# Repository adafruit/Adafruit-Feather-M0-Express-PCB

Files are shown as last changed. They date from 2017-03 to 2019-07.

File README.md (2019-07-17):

## Adafruit Feather M0 Express - Designed for CircuitPython - ATSAMD21 Cortex M0 PCB

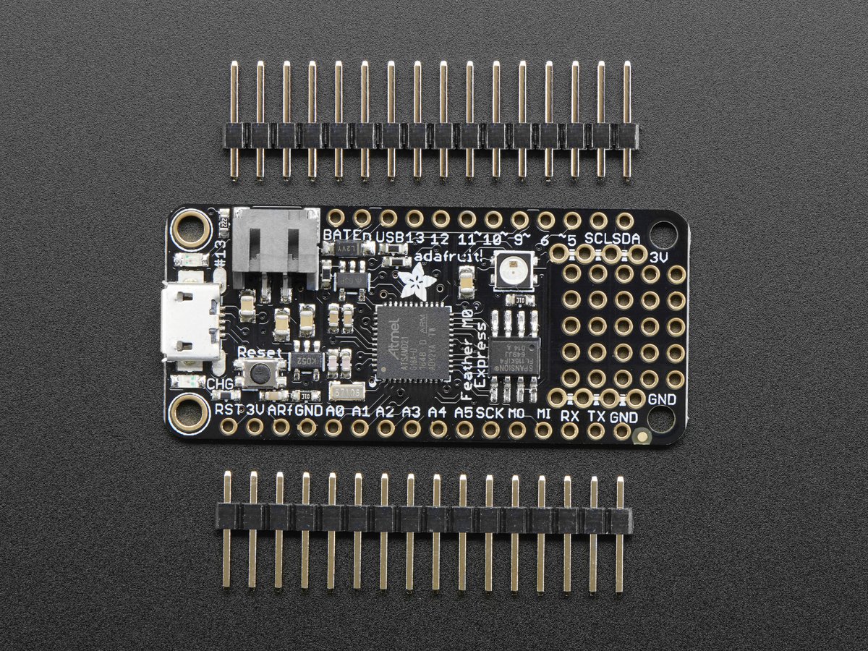
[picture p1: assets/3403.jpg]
<a href="http://www.adafruit.com/products/3403"><br/>
Click here to purchase one from the Adafruit shop</a>

PCB files for the Adafruit Feather M0 Express - Designed for CircuitPython - ATSAMD21 Cortex M0. Format is EagleCAD schematic and board layout
* https://www.adafruit.com/product/3403

### Description

We love all our Feathers equally, but this Feather is very special. It's our first Feather that is specifically designed for use with CircuitPython! CircuitPython is our beginner-oriented flavor of MicroPython - and as the name hints at, its a small but full-featured version of the popular Python programming language specifically for use with circuitry and electronics.

Please note, CircuitPython does not come preloaded. See the full guide linked below for instructions on installing it.

That doesn't mean you cant also use it with Arduino IDE! At the Feather M0's heart is an ATSAMD21G18 ARM Cortex M0+ processor, clocked at 48 MHz and at 3.3V logic, the same one used in the new [Arduino Zero](https://www.adafruit.com/products/2843). This chip has a whopping 256K of FLASH (8x more than the Atmega328 or 32u4) and 32K of RAM (16x as much)! This chip comes with built in USB so it has USB-to-Serial program & debug capability built in with no need for an FTDI-like chip.

**Here's some handy specs!**
 * Measures 2.0" x 0.9" x 0.28" (51mm x 23mm x 8mm) without headers soldered in
 * Light as a (large?) feather - 5 grams
 * ATSAMD21G18 @ 48MHz with 3.3V logic/power
 * 256KB of FLASH + 32KB of RAM
 * No EEPROM
 * 32.768 KHz crystal for clock generation & RTC
 * 3.3V regulator with 500mA peak current output
 * USB native support, comes with USB bootloader and serial port debugging
 * You also get tons of pins - 20 GPIO pins
 * Hardware Serial, hardware I2C, hardware SPI support
 * PWM outputs on all pins
 * 6 x 12-bit analog inputs
 * 1 x 10-bit analog ouput (DAC)
 * Built in 100mA lipoly charger with charging status indicator LED
 * Pin #13 red LED for general purpose blinking
 * Power/enable pin
 * 4 mounting holes
 * Reset button

The **Feather M0 Express** uses the extra space left over to add a **Mini NeoPixel, 2 MB SPI Flash** storage and a little prototyping space. You can use the SPI Flash storage like a very tiny hard drive. When used in CircuitPython, the 2 MB flash acts as storage for all your scripts, libraries and files. When used in Arduino, you can read/write files to it, like a little datalogger or SD card, and then with our helper program, access the files over USB.

**Easy reprogramming**: the Feather M0 comes pre-loaded with the [UF2 bootloader](https://learn.adafruit.com/adafruit-feather-m0-express-designed-for-circuit-python-circuitpython/uf2-bootloader), which looks like a USB storage key. Simply drag firmware on to program, no special tools or drivers needed! It can be used to load up CircuitPython, PXT MakeCode or Arduino IDE (it is bossa-compatible)

Comes fully assembled and tested, with the UF2 USB bootloader. We also toss in some header so you can solder it in and plug into a solderless breadboard. 

**Lipoly battery and USB cable not included** (but we do have lots of options in the shop if you'd like!)

[Wanna get started with this fancy new Feather? We have a full guide with details on using it with both Arduino IDE and CircuitPython. The guide also has wiring information, drivers, Fritzing objects, schematics, datasheets and more!](https://learn.adafruit.com/adafruit-feather-m0-express-designed-for-circuit-python-circuitpython)

### License

Adafruit invests time and resources providing this open source design, please support Adafruit and open-source hardware by purchasing products from [Adafruit](https://www.adafruit.com)!

Designed by Limor Fried/Ladyada for Adafruit Industries.

Creative Commons Attribution/Share-Alike, all text above must be included in any redistribution. See license.txt for additional details.

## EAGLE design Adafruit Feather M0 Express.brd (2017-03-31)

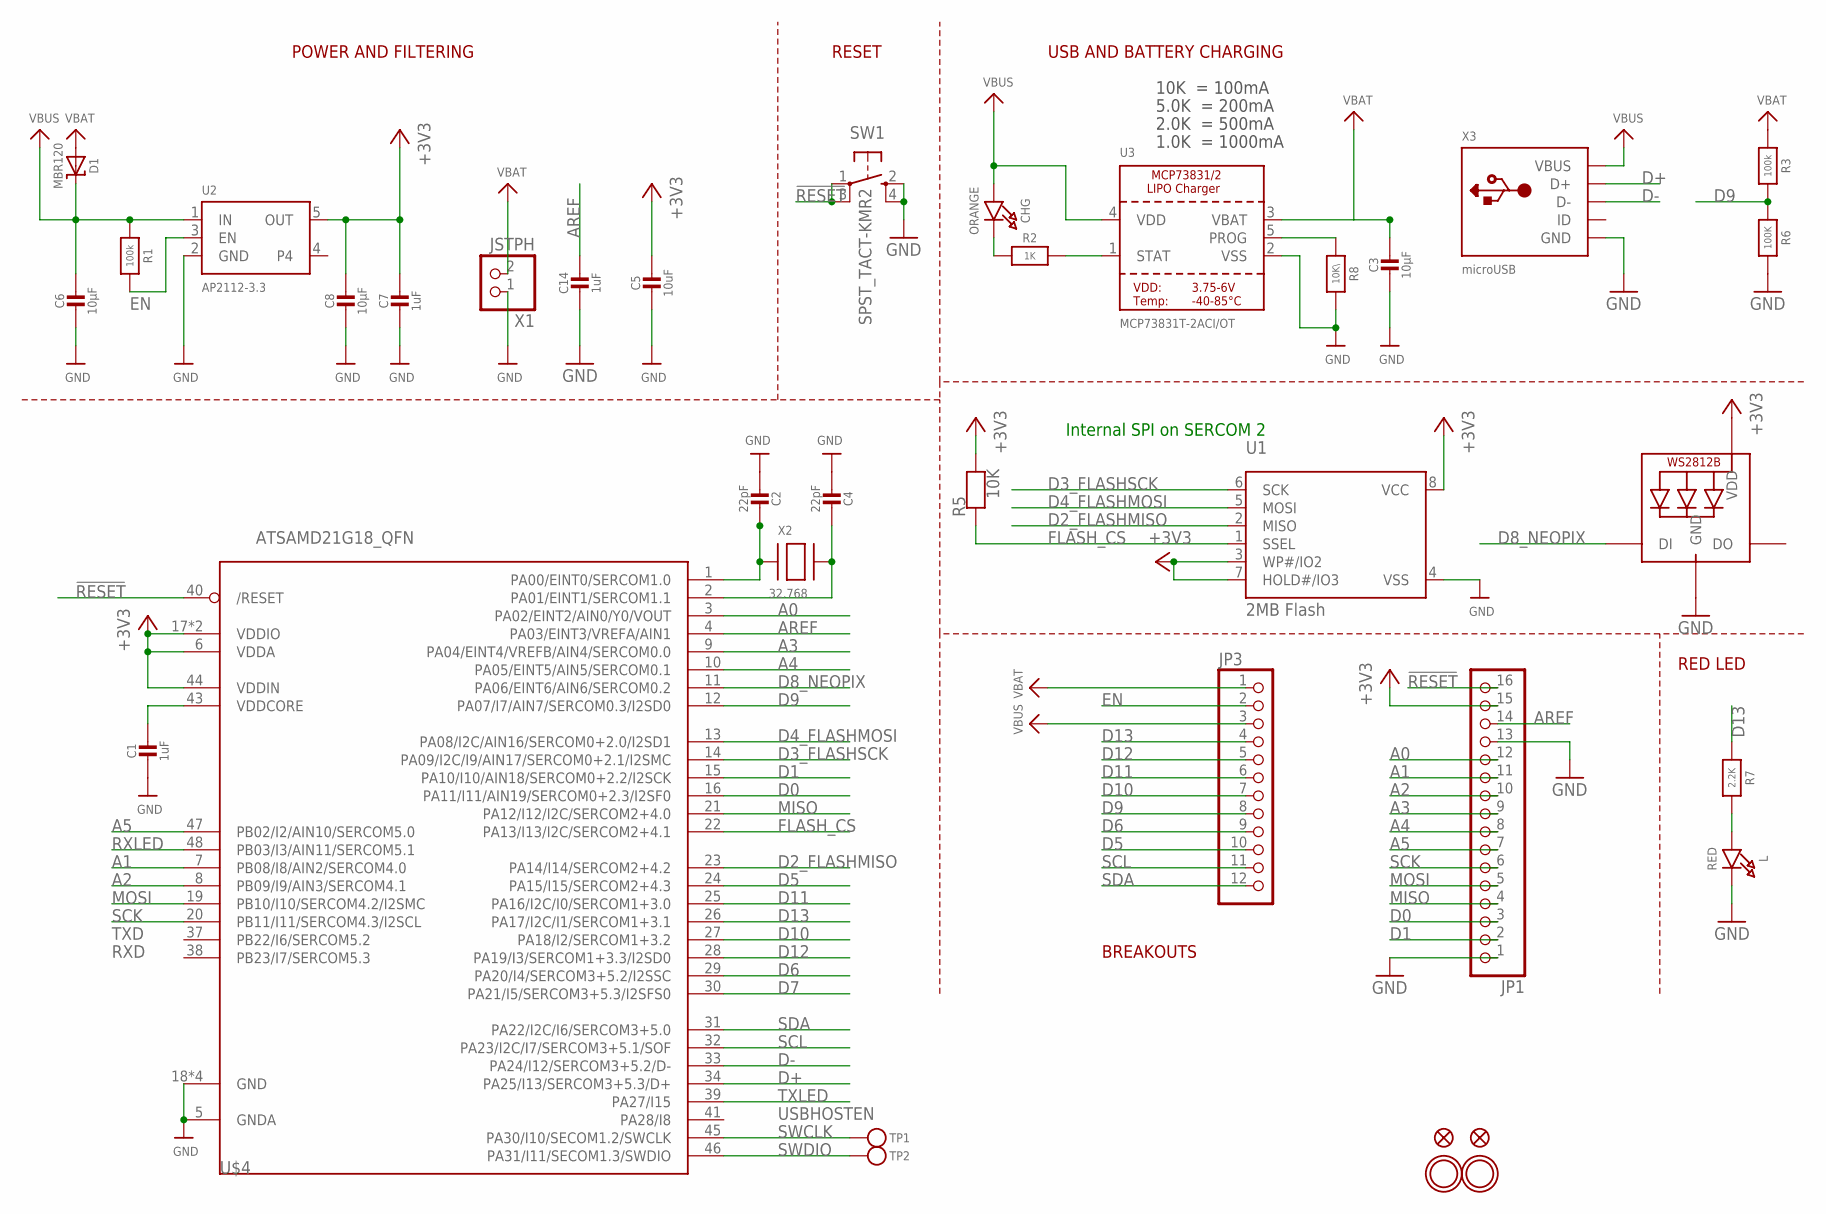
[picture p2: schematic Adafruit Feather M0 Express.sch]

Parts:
C1, C7, C14: 1uF; 0603-NO
C2, C4: 22pF; 0603-NO
C3, C6, C8: 10µF; 0805-NO
C5: 10uF; 0805-NO
CHG: ORANGE; CHIPLED_0805_NOOUTLINE
D1: MBR120; SOD-123
JP1: HEADER-1X16ROUND; 1X16_ROUND
JP3: HEADER-1X12; 1X12_ROUND
L: RED; CHIPLED_0805_NOOUTLINE
LED1: WS2812B3535; LED3535
R1, R3: 100k; 0603-NO
R2: 1K; 0603-NO
R5: 10K; 0603-NO
R6: 100K; 0603-NO
R7: 2.2K; 0603-NO
R8: 10K\; 0603-NO
SW1: SPST_TACT-KMR2; KMR2
TP1, TP2: TESTPOINTROUND1.5MM; TESTPOINT_ROUND_1.5MM
U1: 2MB Flash; SOIC8_208MIL
U2: AP2112-3.3; SOT23-5
U3: MCP73831T-2ACI/OT; SOT23-5
U$4: ATSAMD21G18_QFN; TQFN48_7MM
U$31, U$32: MOUNTINGHOLE2.5; MOUNTINGHOLE_2.5_PLATED
U$34, U$35: FIDUCIAL""; FIDUCIAL_1MM
X1: JSTPH; JSTPH2
X2: 32.768; XTAL3215
X3: microUSB; 4UCONN_20329_V2

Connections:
!RESET: JP1.16, SW1.1, SW1.3 (P1), U$4.40 (/RESET)
+3V3: C5.1, C7.1, C8.1, JP1.15, LED1.2 (VDD), R5.2, U1.3 (WP#/IO2), U1.7 (HOLD#/IO3), U1.8 (VCC), U2.5 (OUT), U$4.6 (VDDA), U$4.17 (VDDIO), U$4.36 (VDDIO), U$4.44 (VDDIN)
A0: JP1.12, U$4.3 (PA02/EINT2/AIN0/Y0/VOUT)
A1: JP1.11, U$4.7 (PB08/I8/AIN2/SERCOM4.0)
A2: JP1.10, U$4.8 (PB09/I9/AIN3/SERCOM4.1)
A3: JP1.9, U$4.9 (PA04/EINT4/VREFB/AIN4/SERCOM0.0)
A4: JP1.8, U$4.10 (PA05/EINT5/AIN5/SERCOM0.1)
A5: JP1.7, U$4.47 (PB02/I2/AIN10/SERCOM5.0)
AREF: C14.1, JP1.14, U$4.4 (PA03/EINT3/VREFA/AIN1)
D0: JP1.3, U$4.16 (PA11/I11/AIN19/SERCOM0+2.3/I2SF0)
D1: JP1.2, U$4.15 (PA10/I10/AIN18/SERCOM0+2.2/I2SCK)
D2_FLASHMISO: U1.2 (MISO), U$4.23 (PA14/I14/SERCOM2+4.2)
D3_FLASHSCK: U1.6 (SCK), U$4.14 (PA09/I2C/I9/AIN17/SERCOM0+2.1/I2SMC)
D4_FLASHMOSI: U1.5 (MOSI), U$4.13 (PA08/I2C/AIN16/SERCOM0+2.0/I2SD1)
D5: JP3.10, U$4.24 (PA15/I15/SERCOM2+4.3)
D6: JP3.9, U$4.29 (PA20/I4/SERCOM3+5.2/I2SSC)
D7: U$4.30 (PA21/I5/SERCOM3+5.3/I2SFS0)
D8_NEOPIX: LED1.1 (DI), U$4.11 (PA06/EINT6/AIN6/SERCOM0.2)
D9: JP3.8, R3.2, R6.1, U$4.12 (PA07/I7/AIN7/SERCOM0.3/I2SD0)
D10: JP3.7, U$4.27 (PA18/I2/SERCOM1+3.2)
D11: JP3.6, U$4.25 (PA16/I2C/I0/SERCOM1+3.0)
D12: JP3.5, U$4.28 (PA19/I3/SERCOM1+3.3/I2SD0)
D13: JP3.4, R7.1, U$4.26 (PA17/I2C/I1/SERCOM1+3.1)
D+: U$4.34 (PA25/I13/SERCOM3+5.3/D+), X3.D+
D-: U$4.33 (PA24/I12/SERCOM3+5.2/D-), X3.D-
EN: JP3.2, R1.2, U2.3 (EN)
FLASH_CS: R5.1, U1.1 (SSEL), U$4.22 (PA13/I13/I2C/SERCOM2+4.1)
GND: C1.2, C2.2, C3.2, C4.2, C5.2, C6.2, C7.2, C8.2, C14.2, JP1.1, JP1.13, L.C, LED1.4 (GND), R6.2, R8.2, SW1.2 (S), SW1.4 (S1), U1.4 (VSS), U2.2 (GND), U3.2 (VSS), U$4.5 (GNDA), U$4.18 (GND), U$4.35 (GND), U$4.42 (GND), U$4.THERMAL (GND), X1.1, X3.BASE@1 (GND), X3.BASE@2 (GND), X3.GND, X3.SPRT@1 (GND), X3.SPRT@2 (GND), X3.SPRT@3 (GND), X3.SPRT@4 (GND)
MISO: JP1.4, U$4.21 (PA12/I12/I2C/SERCOM2+4.0)
MOSI: JP1.5, U$4.19 (PB10/I10/SERCOM4.2/I2SMC)
unnamed: CHG.C, R2.1
unnamed: L.A, R7.2
unnamed: R2.2, U3.1 (STAT)
unnamed: R8.1, U3.5 (PROG)
unnamed: C2.1, U$4.1 (PA00/EINT0/SERCOM1.0), X2.P$1
unnamed: C4.1, U$4.2 (PA01/EINT1/SERCOM1.1), X2.P$2
RXLED: U$4.48 (PB03/I3/AIN11/SERCOM5.1)
SCK: JP1.6, U$4.20 (PB11/I11/SERCOM4.3/I2SCL)
SCL: JP3.11, U$4.32 (PA23/I2C/I7/SERCOM3+5.1/SOF)
SDA: JP3.12, U$4.31 (PA22/I2C/I6/SERCOM3+5.0)
SWCLK: TP1.P$1, U$4.45 (PA30/I10/SECOM1.2/SWCLK)
SWDIO: TP2.P$1, U$4.46 (PA31/I11/SECOM1.3/SWDIO)
TXLED: U$4.39 (PA27/I15)
VBAT: C3.1, D1.A, JP3.1, R3.1, U3.3 (VBAT), X1.2
VBUS: C6.1, CHG.A, D1.C, JP3.3, R1.1, U2.1 (IN), U3.4 (VDD), X3.VBUS
VDDCORE: C1.1, U$4.43 (VDDCORE)

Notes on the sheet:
POWER AND FILTERING
RESET
10K = 100mA
5.0K = 200mA
2.0K = 500mA
1.0K = 1000mA
USBHOSTEN
TXD
RXD
USB AND BATTERY CHARGING
BREAKOUTS
RED LED
Internal SPI on SERCOM 2

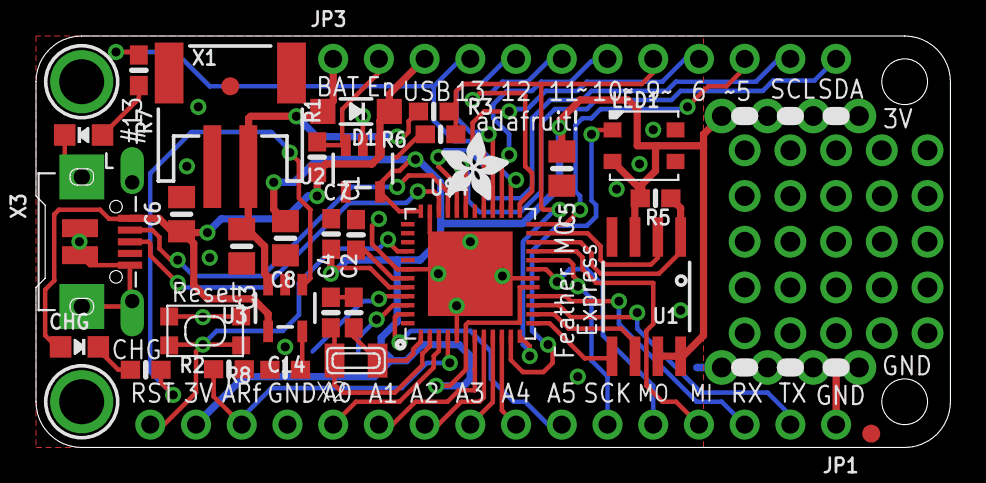
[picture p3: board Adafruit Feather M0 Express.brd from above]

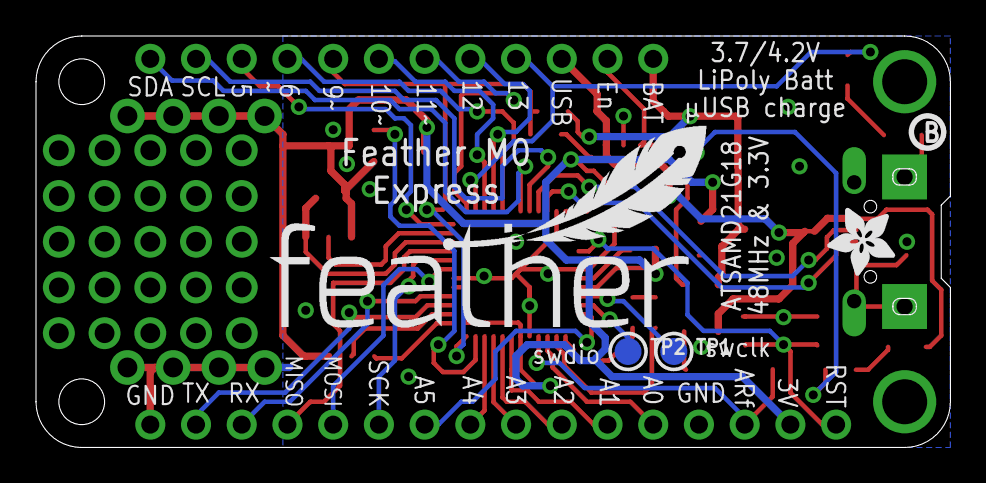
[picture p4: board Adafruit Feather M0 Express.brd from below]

Board: 2 copper layers, 50.8 x 22.9 mm, 40 parts (5 on the bottom side), 43 nets.

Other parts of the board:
U$7, U$12: ADAFRUIT_3.5MM
U$9: FEATHERLOGO
U$13: PCBFEAT-REV-040

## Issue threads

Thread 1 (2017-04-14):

PDF schematics?

ianrrees, 2017-04-14:
Hello!  It would be great if there were a pdf(?) of the schematic here, for folks who don't have Eagle installed for whatever reason.  I'm a KiCad user, and can't quite read the schematic in [this manual](https://cdn-learn.adafruit.com/downloads/pdf/adafruit-feather-m0-express-designed-for-circuit-python-circuitpython.pdf).

I would be glad to make a PR that adds a PDF if that would be accepted?

ladyada, 2017-04-14:
schematic here
https://learn.adafruit.com/bluefruit-nrf52-feather-learning-guide/arduino-bsp-setup?view=all#schematic

ianrrees, 2017-04-14:
Thanks for the quick response!  That schematic is for a different board, but I think I can figure out what I wanted to know from the photos anyways (or just be patient and wait for mine to arrive...).  Looking forward to experimenting with micropython!

caternuson, 2017-04-14:
Check out the 'Downloads' page for a given product's guide. That's where most of this stuff tries to live.

https://learn.adafruit.com/adafruit-feather-m0-express-designed-for-circuit-python-circuitpython/downloads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

ladyada, 2017-04-14:
thanks - that was the right link! we have a lot of feathers :)

Closed 2017-04-14.

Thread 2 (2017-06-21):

Feater M0 Express out of the Box on Win8, no USB Mass Storage in bootmode

mindforger, 2017-06-21:
I followed the guide, plugged it in, without any hub, double pressed the reset button and now its fading the red LED on and off and a new COM Port is showing in the drivers, but no mass storage device. What is wrong with that? I can not load UF2s.

I can not even flash a bootloader, there is only an UF2 Version on the page, pretty much useless for me if i can not access the bootloader.

ladyada, 2017-06-21:
please post in the adafruit forums under circuitpython thx!

mindforger, 2017-06-22:
i just want to let you know that this sounds a bit bold to me and that i want to make clear **i do not want** to register with the forum
sure this is not the exactly right place to deal with a bootloader issue as this repo is for the PCB mostly, but the bootloader is hosted here

Closed 2017-06-21.

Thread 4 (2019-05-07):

LICENSE.txt not in repo

biomurph, 2019-05-07:
Hi Adafruit,

I am looking around at how OSH companies are licensing their products, and i notice that you say that you license under CC-SA, and in the readme you reference a file called LICENSE.txt that is not included in the repo. Looking at a handful of other repos, this seems to be the case across the board.

Can you update your files with an actual license for us to follow?

ladyada, 2019-05-07:
its cc sa by, use wahtevers on cc website plz

Closed 2019-05-07.

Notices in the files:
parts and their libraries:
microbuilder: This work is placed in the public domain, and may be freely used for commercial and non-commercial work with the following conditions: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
